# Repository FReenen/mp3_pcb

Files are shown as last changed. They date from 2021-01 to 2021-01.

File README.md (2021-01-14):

# ANE10 PCB 2 - MP3 Speler

   This is work in progress!

A MP3 player with a ethernet interface.

## interface

   Work in progress.

## voeding

Thare a two power supplies on the board. One for het analog circuitry and
one for the part. Thes power rails are isolated. If you want to use
two separate power supplies to improve audio quality you can.

Both power supplies don't have to be regulated and support a range of 10
to 30 V.

## housing

   Work in progress.

The idea is to make a sort of rack to 'click' it in as a card,
that's why there is a weird cutout on the board.

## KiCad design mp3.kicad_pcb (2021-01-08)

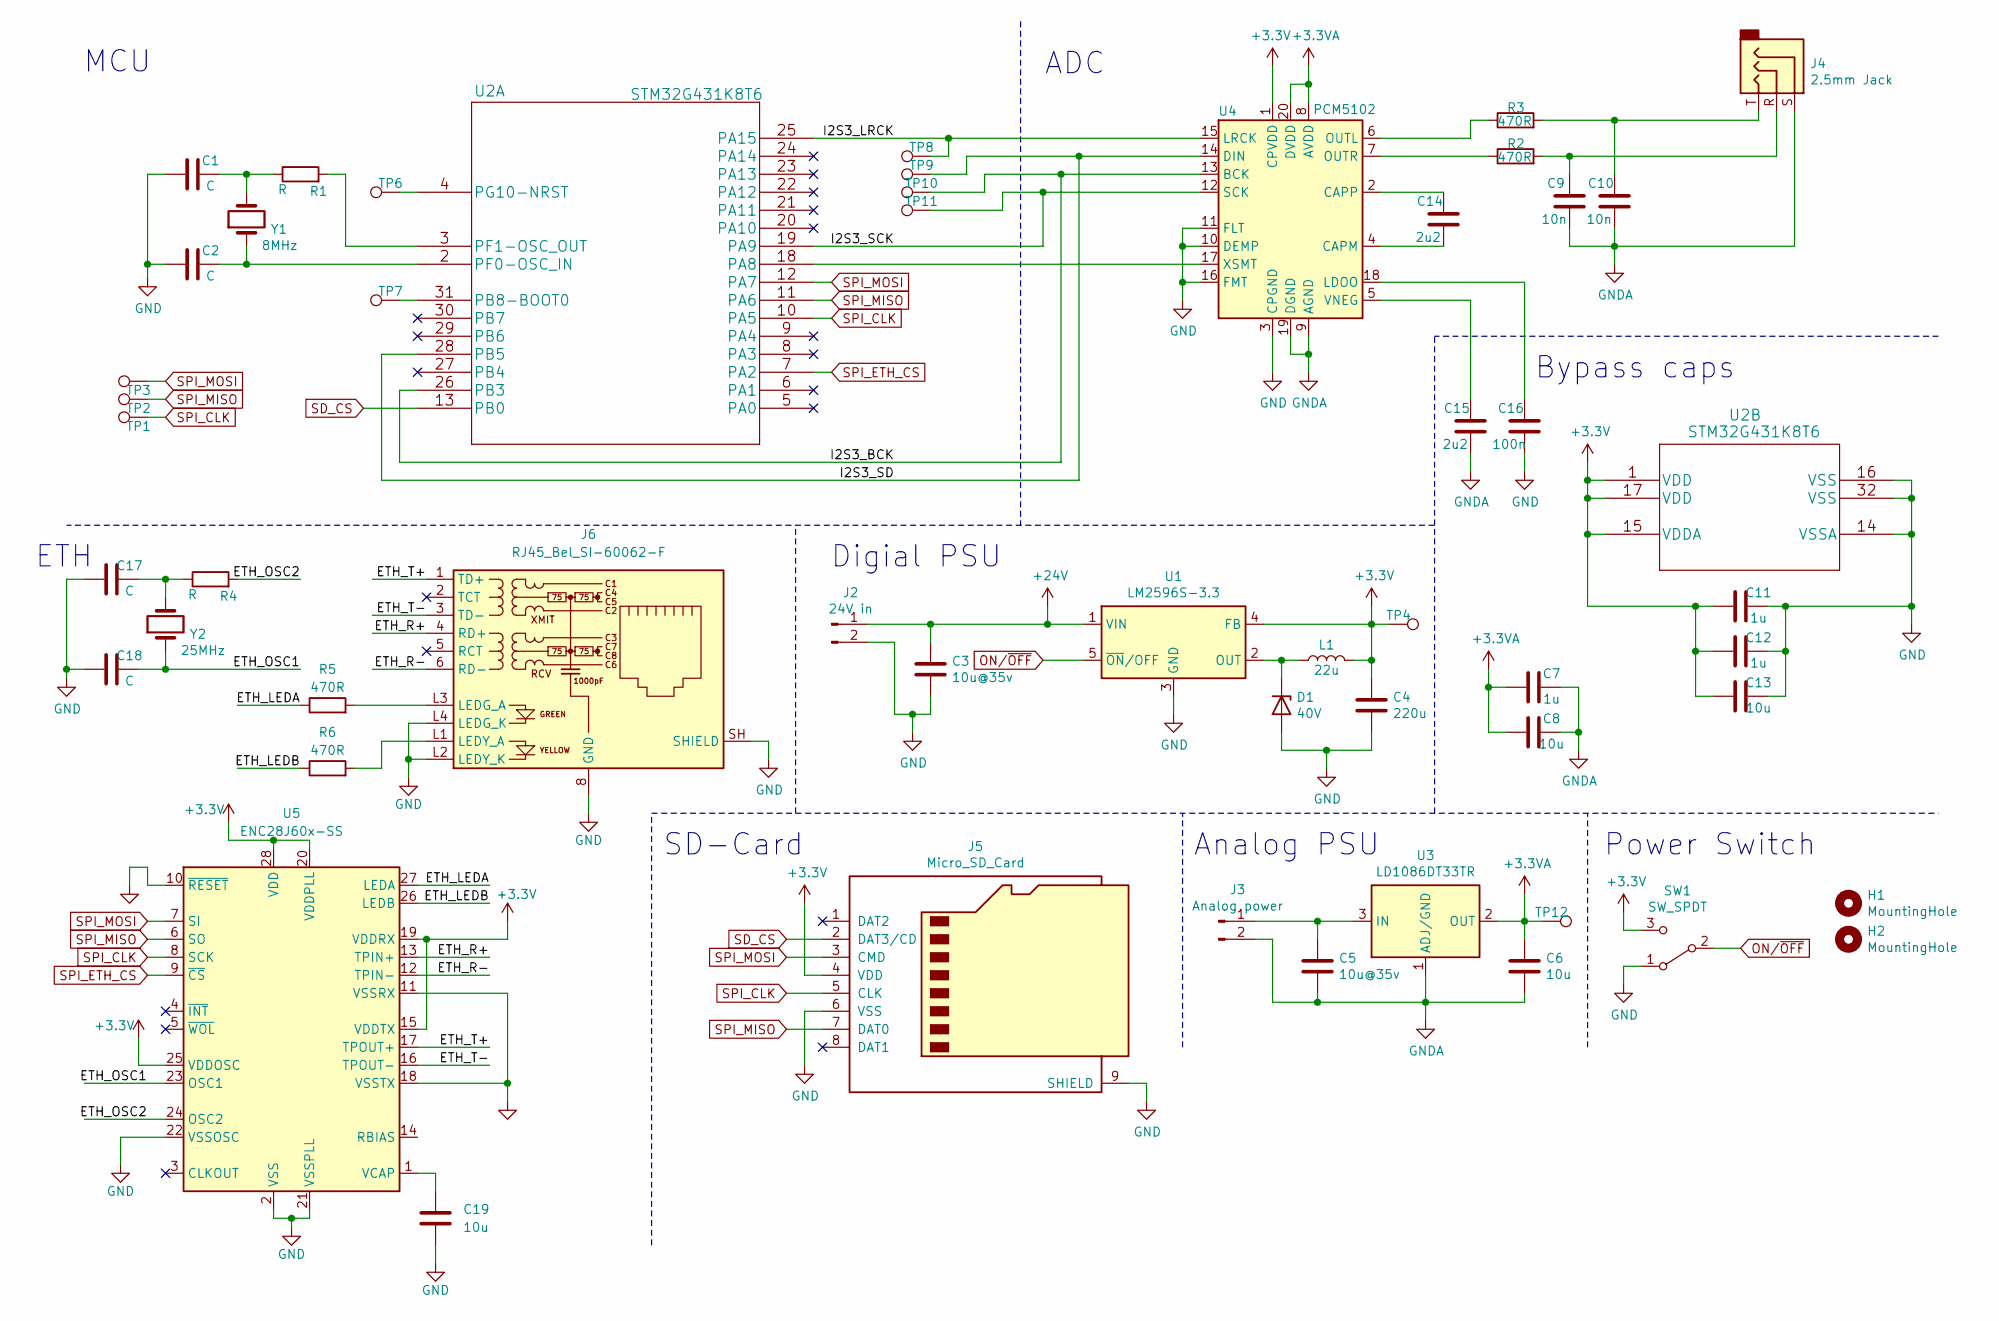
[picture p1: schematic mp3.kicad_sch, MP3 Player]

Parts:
C1, C2, C17, C18: C; C_0805_2012Metric
C3, C5: 10u@35v; C_1206_3216Metric
C4: 220u; C_1206_3216Metric
C6, C8, C13, C19: 10u; C_0805_2012Metric
C7, C11, C12: 1u; C_0603_1608Metric
C9, C10: 10n; C_0805_2012Metric
C14, C15: 2u2; C_0805_2012Metric
C16: 100n; C_0805_2012Metric
D1: 40V; D_SOD-123F
H1, H2: MountingHole; MountingHole_3.2mm_M3
J2: 24V in; Molex_KK-254_AE-6410-02A_1x02_P2.54mm_Vertical
J3: Analog power; Molex_KK-254_AE-6410-02A_1x02_P2.54mm_Vertical
J4: 2.5mm Jack; Jack_3.5mm_CUI_SJ1-3533NG_Horizontal
J5: Micro_SD_Card; microSD_HC_Hirose_DM3D-SF
J6: RJ45_Bel_SI-60062-F
L1: 22u; L_12x12mm_H8mm
R1, R4: R; R_0805_2012Metric
R2, R3, R5, R6: 470R; R_0805_2012Metric
SW1: SW_SPDT; SW_E-Switch_EG1224_SPDT_Angled
TP1, TP2, TP3, TP4, TP6, TP7, TP8, TP9, TP10, TP11, TP12: TestPoint; TestPoint_Pad_D1.0mm
U1: LM2596S-3.3; TO-263-5_TabPin3
U2: STM32G431K8T6; LQFP-32_7x7mm_P0.8mm
U3: LD1086DT33TR; TO-252-2
U4: PCM5102; TSSOP-20_4.4x6.5mm_P0.65mm
U5: ENC28J60x-SS; SSOP-28_5.3x10.2mm_P0.65mm
Y1: 8MHz; Crystal_HC49-4H_Vertical
Y2: 25MHz; Crystal_HC49-4H_Vertical

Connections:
+3.3VA: C6.1, C7.1, C8.1, TP12.1, U3.2 (OUT), U4.8 (AVDD), U4.20 (DVDD)
+3V3: C4.1, C11.1, C12.1, C13.1, J5.4 (VDD), L1.2, SW1.3 (C), TP4.1, U1.4 (FB), U2.1 (VDD), U2.15 (VDDA), U2.17 (VDD), U4.1 (CPVDD), U5.15 (VDDTX), U5.19 (VDDRX), U5.20 (VDDPLL), U5.25 (VDDOSC), U5.28 (VDD)
+24V: C3.1, J2.1, U1.1 (VIN)
/ETH_LEDA: R5.1, U5.27 (LEDA)
/ETH_LEDB: R6.1, U5.26 (LEDB)
/ETH_OSC1: C18.2, U5.23 (OSC1), Y2.1
/ETH_OSC2: R4.2, U5.24 (OSC2)
/ETH_R+: J6.4 (RD+), U5.13 (TPIN+)
/ETH_R-: J6.6 (RD-), U5.12 (TPIN-)
/ETH_T+: J6.1 (TD+), U5.17 (TPOUT+)
/ETH_T-: J6.3 (TD-), U5.16 (TPOUT-)
/I2S3_BCK: TP10.1, U2.26 (PB3), U4.13 (BCK)
/I2S3_LRCK: TP8.1, U2.25 (PA15), U4.15 (LRCK)
/I2S3_SCK: TP11.1, U2.19 (PA9), U4.12 (SCK)
/I2S3_SD: TP9.1, U2.28 (PB5), U4.14 (DIN)
GND: C1.1, C2.1, C3.2, C4.2, C11.2, C12.2, C13.2, C16.1, C17.1, C18.1, C19.2, D1.2 (A), J2.2, J5.6 (VSS), J5.9 (SHIELD), J6.8 (GND), J6.L2 (LEDY_K), J6.L4 (LEDG_K), J6.SH (SHIELD), SW1.1 (A), U1.3 (GND), U2.14 (VSSA), U2.16 (VSS), U2.32 (VSS), U4.3 (CPGND), U4.10 (DEMP), U4.11 (FLT), U4.16 (FMT), U5.2 (VSS), U5.10 (~RESET), U5.11 (VSSRX), U5.18 (VSSTX), U5.21 (VSSPLL), U5.22 (VSSOSC)
GNDA: C5.2, C6.2, C7.2, C8.2, C9.1, C10.1, C15.1, J3.2, J4.S, U3.1 (ADJ/GND), U4.9 (AGND), U4.19 (DGND)
unnamed: C5.1, J3.1, U3.3 (IN)
unnamed: C9.2, J4.R, R2.2
unnamed: C10.2, J4.T, R3.2
unnamed: C14.1, U4.4 (CAPM)
unnamed: C14.2, U4.2 (CAPP)
unnamed: C15.2, U4.5 (VNEG)
unnamed: C16.2, U4.18 (LDOO)
unnamed: C17.2, R4.1, Y2.2
unnamed: C19.1, U5.1 (VCAP)
unnamed: D1.1 (K), L1.1, U1.2 (OUT)
unnamed: J6.L1 (LEDY_A), R6.2
unnamed: J6.L3 (LEDG_A), R5.2
unnamed: R2.1, U4.7 (OUTR)
unnamed: R3.1, U4.6 (OUTL)
unnamed: C2.2, U2.2 (PF0-OSC_IN), Y1.1
unnamed: R1.2, U2.3 (PF1-OSC_OUT)
unnamed: TP6.1, U2.4 (PG10-NRST)
unnamed: U2.18 (PA8), U4.17 (XSMT)
unnamed: TP7.1, U2.31 (PB8-BOOT0)
unnamed: C1.2, R1.1, Y1.2
ON/~OFF: SW1.2 (B), U1.5 (~ON~/OFF)
SD_CS: J5.2 (DAT3/CD), U2.13 (PB0)
SPI_CLK: J5.5 (CLK), TP1.1, U2.10 (PA5), U5.8 (SCK)
SPI_ETH_CS: U2.7 (PA2), U5.9 (~CS)
SPI_MISO: J5.7 (DAT0), TP2.1, U2.11 (PA6), U5.6 (SO)
SPI_MOSI: J5.3 (CMD), TP3.1, U2.12 (PA7), U5.7 (SI)
no_connect_45: J5.1 (DAT2)
no_connect_46: J5.8 (DAT1)
no_connect_47: J6.2 (TCT)
no_connect_48: J6.5 (RCT)
no_connect_49: U2.20 (PA10)
no_connect_50: U2.21 (PA11)
no_connect_51: U2.22 (PA12)
no_connect_52: U2.23 (PA13)
no_connect_53: U2.24 (PA14)
no_connect_54: U2.27 (PB4)
no_connect_55: U2.29 (PB6)
no_connect_56: U2.30 (PB7)
no_connect_57: U2.5 (PA0)
no_connect_58: U2.6 (PA1)
no_connect_59: U2.8 (PA3)
no_connect_60: U2.9 (PA4)
no_connect_61: U5.3 (CLKOUT)
no_connect_62: U5.4 (~INT)
no_connect_63: U5.5 (~WOL)

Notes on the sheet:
ETH
MCU
SD-Card
Digial PSU
ADC
Analog PSU
Bypass caps
Power Switch

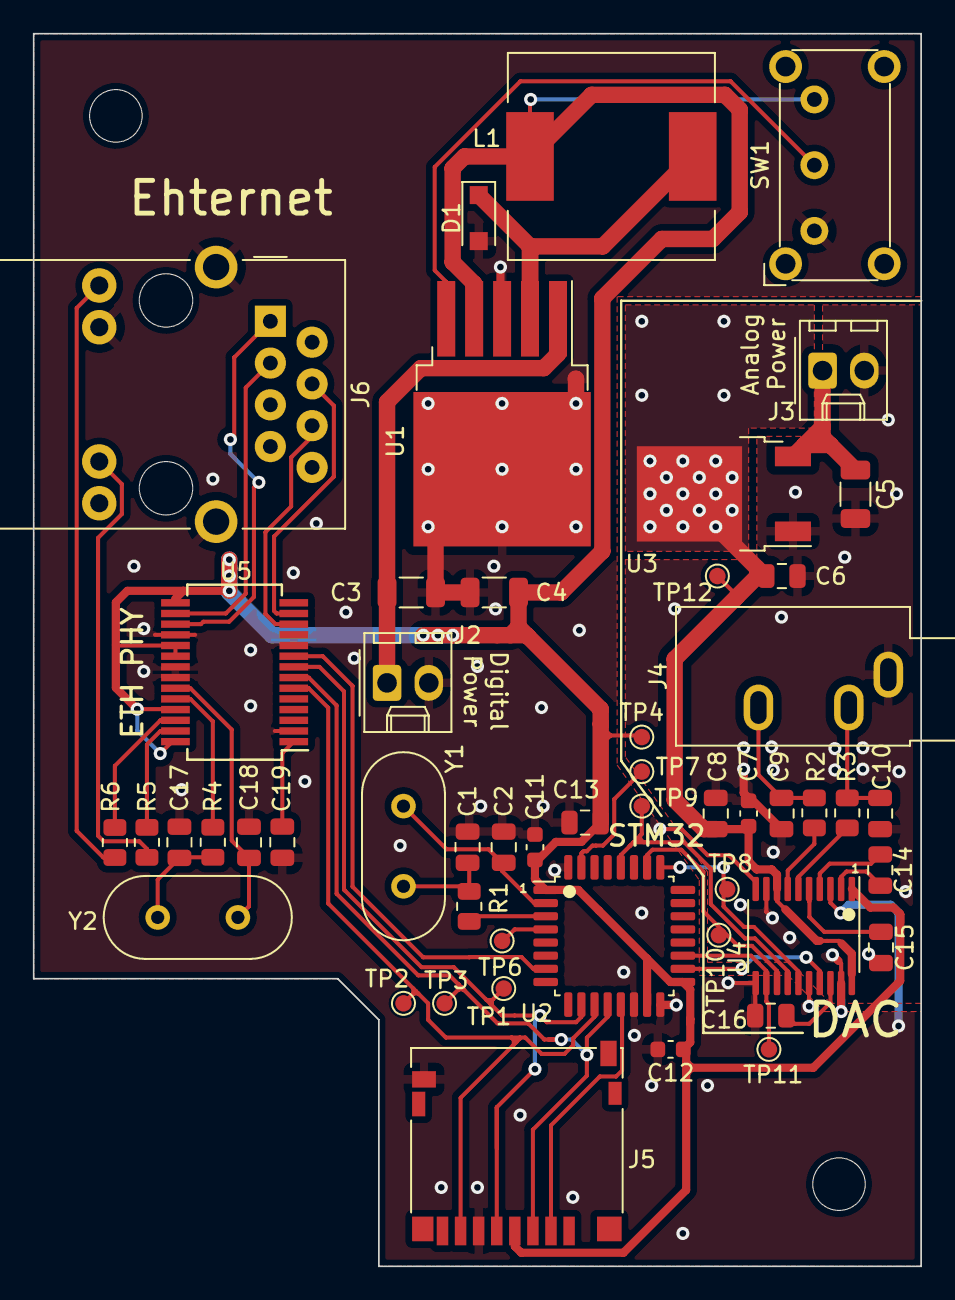
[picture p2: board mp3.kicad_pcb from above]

Board: 2 copper layers, 54.0 x 75.0 mm, 53 parts (0 on the bottom side), 43 nets.
